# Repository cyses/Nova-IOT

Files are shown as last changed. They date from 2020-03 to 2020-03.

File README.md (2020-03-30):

<!DOCTYPE html><html><head><meta charset="utf-8"></head><body id="preview">
<h1 class="code-line" data-line-start=0 data-line-end=1>NovaIoT Cookbook</h1>

<p class="has-line-data" data-line-start="5" data-line-end="6">NovaIoT is an open-source framework that is made for spreading LoRa Sensors all over the world. NovaIoT package consists of two main parts:</p>
<ul>
<li class="has-line-data" data-line-start="6" data-line-end="7">The Hardware design for LoRa modules</li>
<li class="has-line-data" data-line-start="7" data-line-end="8">The Software design for LoRa sensors.</li>
<li class="has-line-data" data-line-start="8" data-line-end="10">And a little bit Magic :)</li>
</ul>
<h1 class="code-line" data-line-start=10 data-line-end=11>New Features!</h1>
<ul>

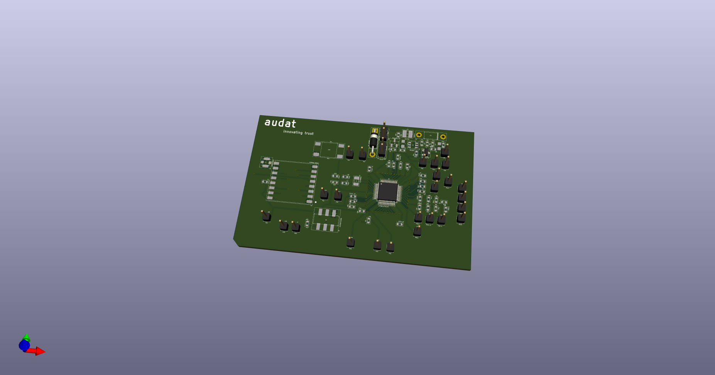
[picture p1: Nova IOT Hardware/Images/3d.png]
Build Status

<li class="has-line-data" data-line-start="12" data-line-end="13">You can visualize the sensor data in the GUI app with a RestFull API.</li>
</ul>
<p class="has-line-data" data-line-start="16" data-line-end="17">You can also:</p>
<ul>
<li class="has-line-data" data-line-start="17" data-line-end="18">Use the hardware design and print the PCB.</li>
<li class="has-line-data" data-line-start="18" data-line-end="19">With required components for PCB you can complete the sensor at all.</li>
<li class="has-line-data" data-line-start="19" data-line-end="20">You can use any IP67 case for the sensor. (We are going to upload the IP67 design soon if you want to use a ready one!)</li>
<li class="has-line-data" data-line-start="20" data-line-end="21">You can integrate the sensor on our server software. (which would be online soon!)</li>
<li class="has-line-data" data-line-start="21" data-line-end="22">You can use our GUI in order to visualize the sensor data (just think like mqtt)</li>
</ul>
<p class="has-line-data" data-line-start="24" data-line-end="25">Here there are several things that we need to mention before we start!</p>
<blockquote>
<p class="has-line-data" data-line-start="26" data-line-end="32">Our primer aim is to spread this LoRa sensors all over the world fastly.<br>
We really believe in the power of open-source<br>
and we are always open to commits and suggestions!<br>
Please feel free if you have an idea for making any of these technologies better<br>
We are ready to hear and make the system better!<br>
or if you just want to use the design, you are very welcome. But do not forget that, it is free for NON-COMMERCIAL use!</p>
</blockquote>
<h3 class="code-line" data-line-start=34 data-line-end=35>Tech</h3>
<p class="has-line-data" data-line-start="36" data-line-end="37">First lets mention what components should you use. The components in the lists required very hard work and took a lot of time in order to find them.</p>
<ul>
<li class="has-line-data" data-line-start="38" data-line-end="39">STM32L072CZT6 - The main microprocessor that we used in our PCB</li>
<li class="has-line-data" data-line-start="39" data-line-end="40">SX1276IMLTRT - the core component for LoRa</li>
<li class="has-line-data" data-line-start="40" data-line-end="41">Li/SOCL2 4000 mAH 3.6v connector 2.54mm Two batteries side by side with protection - this is the magic battery. :)</li>
<li class="has-line-data" data-line-start="41" data-line-end="42">RFM95W-868 - the integrated LoRa module</li>
</ul>
<h3 class="code-line" data-line-start=45 data-line-end=46>Installation</h3>
<p class="has-line-data" data-line-start="47" data-line-end="49">We are changing our software infrastructure in docker based containers. But of course that would take time. Until that time you can use our PHP applications for GUI and server. You can ask us anything if you tackle in somewhere.<br>
The requirements for now are;</p>
<ul>
<li class="has-line-data" data-line-start="50" data-line-end="51">PHP 7.2 +</li>
<li class="has-line-data" data-line-start="51" data-line-end="52">Apache</li>
<li class="has-line-data" data-line-start="52" data-line-end="53">MySQL</li>
</ul>
After completing the setup of docker infrastructure, you would be run the environment as
<pre><code class="has-line-data" data-line-start="56" data-line-end="60" class="language-sh">$ <span class="hljs-built_in">docker</span> compose up

</code></pre>
<h3 class="code-line" data-line-start=63 data-line-end=64>Todos</h3>
<ul>
<li class="has-line-data" data-line-start="65" data-line-end="66"><em>Docker container</em></li>
<li class="has-line-data" data-line-start="66" data-line-end="68">Improvements in hardware design in order to make the PCB smaller</li>
</ul>
<h2 class="code-line" data-line-start=68 data-line-end=70>License</h2>
<p class="has-line-data" data-line-start="71" data-line-end="72">MIT</p>
<p class="has-line-data" data-line-start="74" data-line-end="75"><strong>Free Software, Hell Yeah!</strong></p>
</body></html>

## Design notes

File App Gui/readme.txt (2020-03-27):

Thank you for choosing my software.
I spend some time for making documentation.
Please read documentation before trying to install, it will save time for you.
In case you have some questions or found bugs, don't hasitate to ask me, it's free;)
In case you need some additional functionality, don't hasitate to ask me, it's for money.

My email mail@noxls.net

Sincerely.

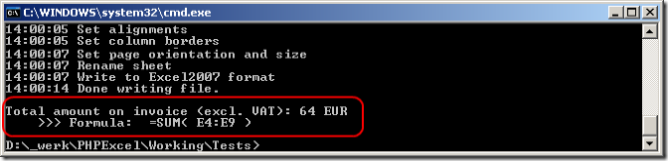
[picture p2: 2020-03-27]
App Gui/includes/classes/PhpSpreadsheet/Documentation/markdown/Overview/images/09-command-line-calculation.png

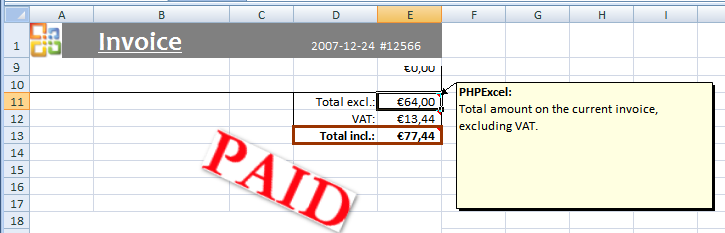
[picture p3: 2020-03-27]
App Gui/includes/classes/PhpSpreadsheet/Documentation/markdown/Overview/images/08-cell-comment.png

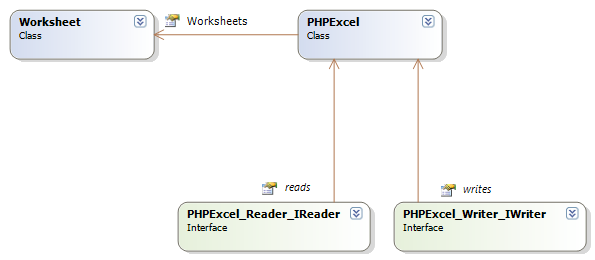
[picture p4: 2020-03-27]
App Gui/includes/classes/PhpSpreadsheet/Documentation/assets/ClassDiagrams/Architecture.png

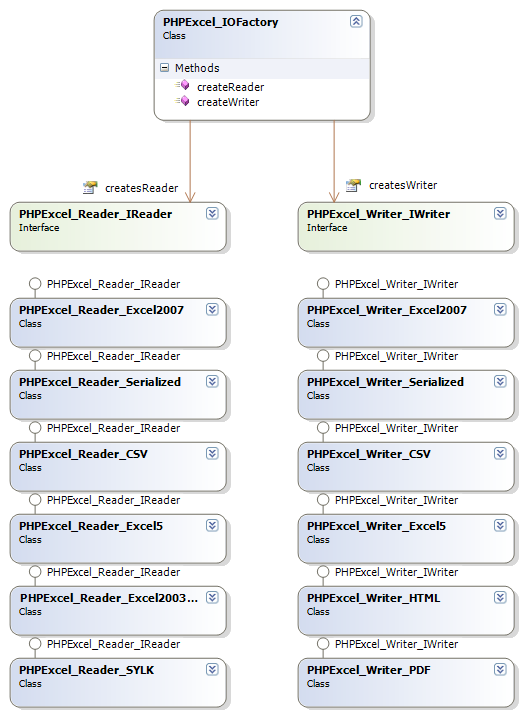
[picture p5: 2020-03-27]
App Gui/includes/classes/PhpSpreadsheet/Documentation/markdown/Overview/images/02-readers-writers.png

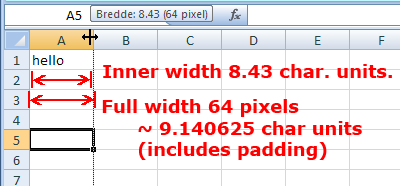
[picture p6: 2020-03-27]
App Gui/includes/classes/PhpSpreadsheet/Documentation/markdown/Overview/images/08-column-width.png

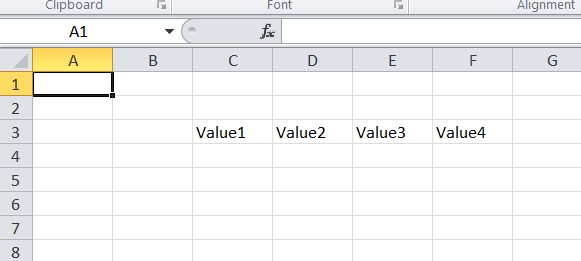
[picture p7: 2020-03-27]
App Gui/includes/classes/PhpSpreadsheet/Documentation/markdown/Overview/images/07-simple-example-3.png

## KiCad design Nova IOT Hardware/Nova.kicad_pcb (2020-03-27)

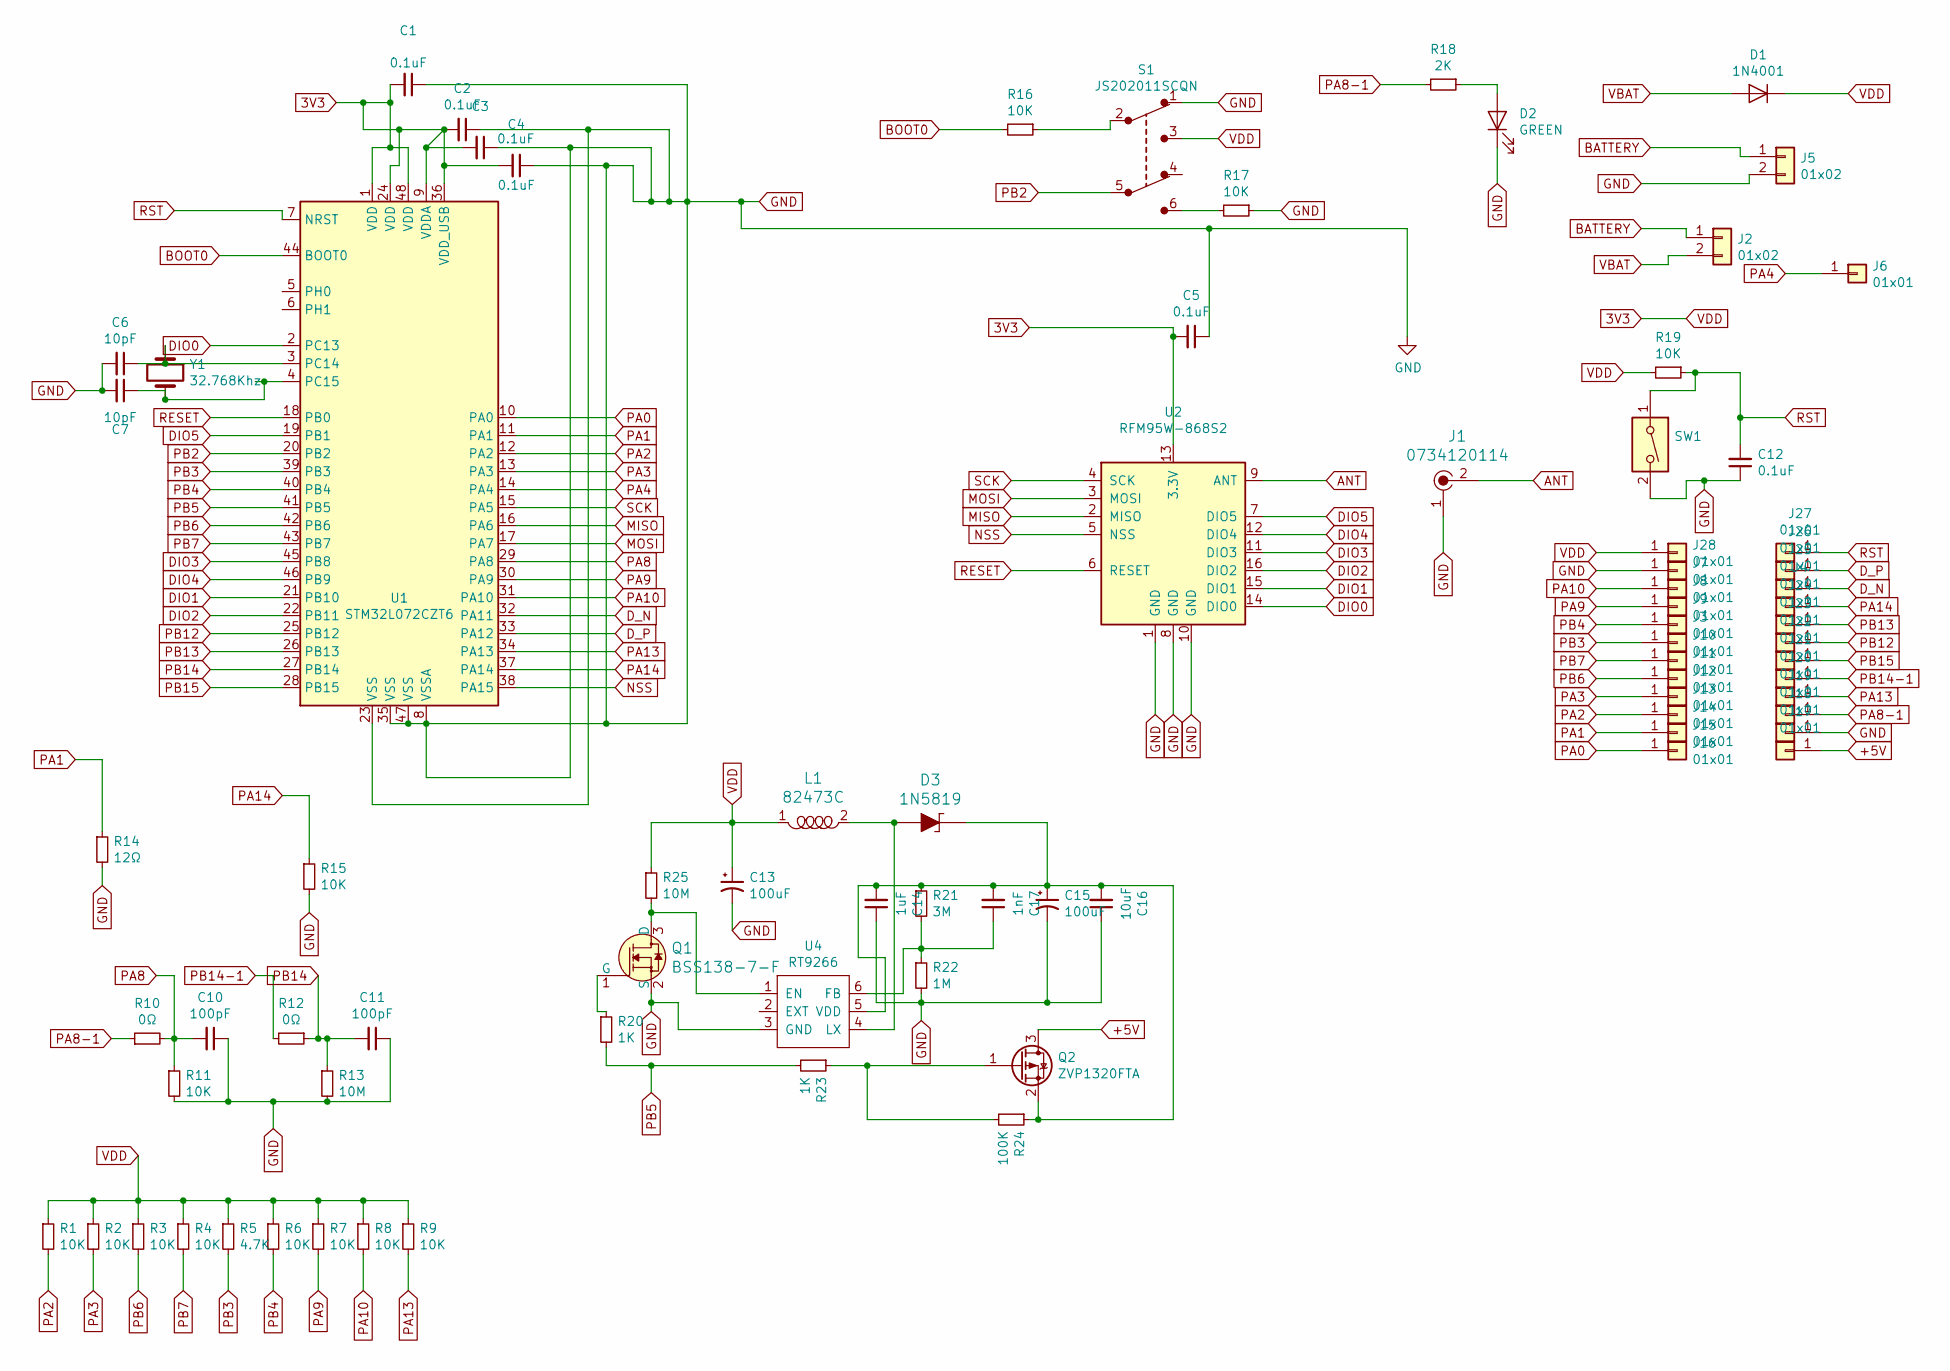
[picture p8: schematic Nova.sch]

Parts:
C1, C2, C3, C4, C5, C12: 0.1uF; 0603
C6, C7: 10pF; 0603
C10, C11: 100pF; 0603
C13, C15: 100uF; 0805
C14: 1uF; 0603
C16: 10uF; 0603
C17: 1nF; 0603
D1: 1N4001; D_DO-41_SOD81_P10.16mm_Horizontal
D2: GREEN; 0603
D3: 1N5819; DO-41; MPN 1N5819; Digi-Key_PN 1N5819FSCT-ND
J1: 0734120114; Molex_734120114_UMC_RF_CONN_Vertical; MPN 0734120114; Digi-Key_PN WM3894CT-ND
J2, J5: 01x02; PinHeader_1x02_P2.54mm_Vertical
J3, J4, J6, J7, J8, J9, J10, J11, J12, J13, J14, J15, J16, J17, J18, J19, J20, J21, J22, J23, J24, J25, J26, J27, J28: 01x01; PinHeader_1x01_P2.54mm_Vertical
L1: 82473C; 1210; MPN 82473C; Digi-Key_PN 811-2477-1-ND
Q1: BSS138-7-F; SOT-23-3; MPN BSS138-7-F; Digi-Key_PN BSS138-FDICT-ND
Q2: ZVP1320FTA; SOT-23
R1, R2, R3, R4, R6, R7, R8, R9, R11, R15, R16, R17, R19: 10K; 0603
R5: 4.7K; 0603
R10, R12: 0Ω; 0603
R13, R25: 10M; 0603
R14: 12Ω; 0603
R18: 2K; 0603
R20, R23: 1K; 0603
R21: 3M; 0603
R22: 1M; 0603
R24: 100K; 0603
S1: JS202011SCQN; Switch_Slide_JS202011SCQN; MPN JS202011SCQN; Digi-Key_PN 401-2002-1-ND
SW1: SW; Switch_Tactile_SMD_6x6mm
U1: STM32L072CZT6; LQFP-48_7x7mm_P0.5mm
U2: RFM95W-868S2; XCVR_RFM95W-868S2
U4: RT9266; SOT-23-6
Y1: 32.768Khz; SMD-2_3.2x1.5mm

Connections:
3V3: C1.2, C2.2, C3.2, C4.2, C5.2, C13.1, D1.1 (K), J28.1, L1.1, R1.1, R2.1, R3.1, R4.1, R5.1, R6.1, R7.1, R8.1, R9.1, R19.2, R25.1, S1.3, U1.1 (VDD), U1.9 (VDDA), U1.24 (VDD), U1.36 (VDD_USB), U1.48 (VDD), U2.13 (3.3V)
+5V: J17.1, Q2.3 (D)
ANT: J1.2, U2.9 (ANT)
BATTERY: J2.1, J5.1
BOOT0: R16.2, U1.44 (BOOT0)
DIO0: U1.2 (PC13), U2.14 (DIO0)
DIO1: U1.21 (PB10), U2.15 (DIO1)
DIO2: U1.22 (PB11), U2.16 (DIO2)
DIO3: U1.45 (PB8), U2.11 (DIO3)
DIO4: U1.46 (PB9), U2.12 (DIO4)
DIO5: U1.19 (PB1), U2.7 (DIO5)
D_N: J25.1, U1.32 (PA11)
D_P: J26.1, U1.33 (PA12)
GND: C1.1, C2.1, C3.1, C4.1, C5.1, C6.2, C7.2, C10.1, C11.1, C12.1, C13.2, C14.1, C15.2, C16.1, D2.1 (K), J1.1, J5.2, J7.1, J18.1, Q1.2 (S), R11.2, R13.2, R14.2, R15.2, R17.1, R22.2, S1.1, SW1.2, U1.8 (VSSA), U1.23 (VSS), U1.35 (VSS), U1.47 (VSS), U2.1 (GND), U2.8 (GND), U2.10 (GND), U4.3 (GND)
MISO: U1.16 (PA6), U2.2 (MISO)
MOSI: U1.17 (PA7), U2.3 (MOSI)
NSS: U1.38 (PA15), U2.5 (NSS)
unnamed: C6.1, U1.3 (PC14), Y1.1
unnamed: C7.1, U1.4 (PC15), Y1.2
unnamed: C14.2, C15.1, C16.2, C17.2, D3.K, Q2.2 (S), R21.1, R24.1, U4.5 (VDD)
unnamed: C17.1, R21.2, R22.1, U4.6 (FB)
unnamed: D2.2 (A), R18.1
unnamed: D3.A, L1.2, U4.4 (LX)
unnamed: Q1.1 (G), R20.1
unnamed: Q1.3 (D), R25.2, U4.1 (EN)
unnamed: Q2.1 (G), R23.1, R24.2
unnamed: R16.1, S1.2
unnamed: R17.2, S1.6
PA0: J16.1, U1.10 (PA0)
PA1: J15.1, R14.1, U1.11 (PA1)
PA2: J14.1, R1.2, U1.12 (PA2)
PA3: J13.1, R2.2, U1.13 (PA3)
PA4: J6.1, U1.14 (PA4)
PA8: C10.2, R10.2, R11.1, U1.29 (PA8)
PA8-1: J19.1, R10.1, R18.2
PA9: J9.1, R7.2, U1.30 (PA9)
PA10: J8.1, R8.2, U1.31 (PA10)
PA13: J20.1, R9.2, U1.34 (PA13)
PA14: J4.1, R15.1, U1.37 (PA14)
PB2: S1.5, U1.20 (PB2)
PB3: J10.1, R5.2, U1.39 (PB3)
PB4: J3.1, R6.2, U1.40 (PB4)
PB5: R20.2, R23.2, U1.41 (PB5)
PB6: J12.1, R3.2, U1.42 (PB6)
PB7: J11.1, R4.2, U1.43 (PB7)
PB12: J23.1, U1.25 (PB12)
PB13: J24.1, U1.26 (PB13)
PB14: C11.2, R12.1, R13.1, U1.27 (PB14)
PB14-1: J21.1, R12.2
PB15: J22.1, U1.28 (PB15)
RESET: U1.18 (PB0), U2.6 (RESET)
RST: C12.2, J27.1, R19.1, SW1.1, U1.7 (NRST)
SCK: U1.15 (PA5), U2.4 (SCK)
VBAT: D1.2 (A), J2.2

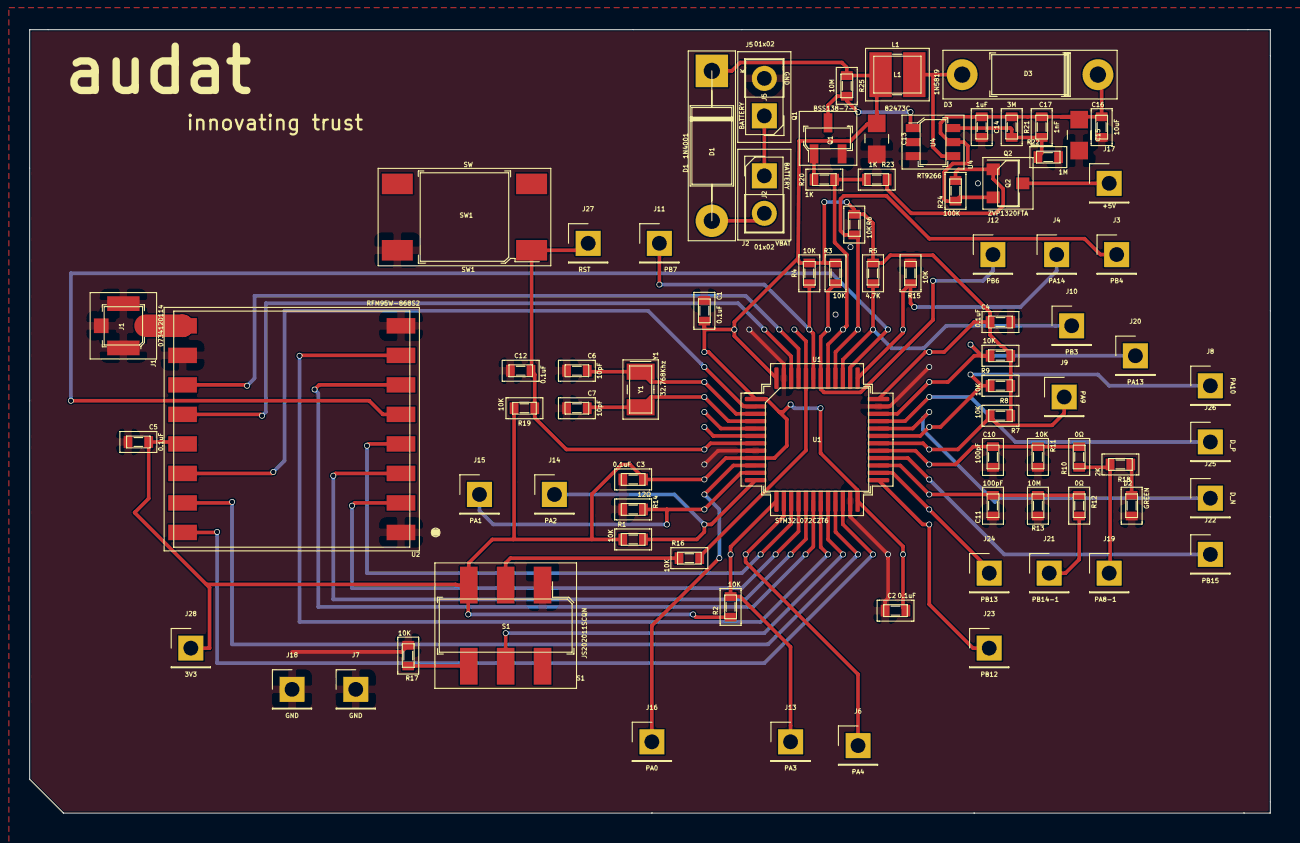
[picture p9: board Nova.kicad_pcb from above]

Board: 2 copper layers, 84.1 x 53.1 mm, 80 parts (0 on the bottom side), 54 nets.

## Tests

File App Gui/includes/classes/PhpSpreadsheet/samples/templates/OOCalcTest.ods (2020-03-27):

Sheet: Sample Data
Test String 1 | 1 | 5 |  | A | E |  | 6 |  | AE
Test - String 2 | 2 | 6 |  | B | F |  | 8 |  | BF |  |  | Dot
Test #3 | 3 | 7 |  | C | G |  | 10 |  | CG | Red | Red | Dash
Test with (") in string | 4 | 8 |  | D | H |  | 12 |  | DH | Orange | Orange | Dash/Dot/Dot
 |  |  |  |  |  |  | 10 | 26 | 36 | Yellow | Yellow | Dash/Dot
Test #3 | 1.23 | TRUE | TRUE |  |  |  |  |  |  | Green | Green | Thin Line
Test #3 | 2.34 | FALSE | FALSE |  |  |  | #NAME? |  |  | Blue | Blue | Thick Dash/Dot/Dot
Test #3 | 3.45 |  |  |  |  |  |  |  |  | Purple | Purple | Variant Thick Dash/Dot/Dot
 |  |  |  |  |  |  |  |  |  | Pink | Pink | Thick Dash/Dot
19/12/1960 |  | TOP |  |  |  | 0 |  |  |  | Brown | Brown | Thick Dash
1 1/2 |  |  |  |  |  | #DIV/0! |  |  |  |  |  | Thick Line
 |  | BOTTOM |  |  |  |  |  |  |  |  |  | Extra Thick Line
02:30:00 |  |  |  |  | Мойва сушеная |  |  |  |  |  |  | Double Line
 |  | LEFT |  |  | Ärendetext
19/12/60 01:30 |  |  |  |  | Højde
 |  | RIGHT
 | BOX |  |  |  |  | Test Column 1
 |  |  |  |  |  |  | Test Column 2 |  |  | Patterned | Patterned 2
 |  |  |  |  |  |  |  | Test Column 3
Underline None |  | Rotate 90 |  | Rotate 45 |  | Rotate -90 |  | Rotate -45
Underline 1 | Subscript
Underline 2 | Superscript
Underline 3
Underline 4
I don't know if OOCalc supports Rich Text in the same way as Excel, And this row should be autofit height with text wrap
PHPExcel (http://www.phpexcel.net/)

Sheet: Report Data
Heading 1 | Heading 2 | Third Heading | Date Heading | Time Heading | Adjusted Date | Adjusted Number
ABC | 1 | 1.11 | 01-Jan-2001 | 01:00 AM | 31-Dec-2000 | 1.11 | A | 1A
BCD | 2 | 2.22 | 02-Feb-2002 | 02:00 AM | 31-Jan-2002 | 4.44 | B | 2B
CDE | 3 | 3.33 | 03-Mar-2003 | 03:00 AM | 28-Feb-2003 | 9.99 | C | 3C
DEF | 4 | 4.44 | 03-Apr-2004 | 04:00 AM | 30-Mar-2004 | 17.76 | D | 4D
EFG | 5 | 5.55 | 04-May-2005 | 05:00 AM | 29-Apr-2005 | 27.75 | E | 5E
FGH | 6 | 6.66 | 05-Jun-2006 | 06:00 AM | 30-May-2006 | 39.96 | F | 6F
GHI | 7 | 7.77 | 06-Jul-2007 | 07:00 AM | 29-Jun-2007 | 54.39 | G | 7G
HIJ | 8 | 8.88 | 07-Aug-2008 | 08:00 AM | 30-Jul-2008 | 71.04 | H | 8H
IJK | 9 | 9.99 | 08-Sep-2009 | 09:00 AM | 30-Aug-2009 | 89.91 | I | 9I
JKL | 10 | 11.10 | 09-Oct-2010 | 10:00 AM | 29-Sep-2010 | 111.00 | J | 10J
KLM | 11 | 12.21 | 11-Nov-2011 | 11:00 AM | 31-Oct-2011 | 134.31 | K | 11K
LMN | 12 | 13.32 | 12-Dec-2012 | 12:00 AM | 30-Nov-2012 | 159.84 | L | 12L
ZYX | -1 | 1.11 | 01-Dec-1999 | 11:00 PM | 02-Dec-1999 | 1.11 | M | -1M

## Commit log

2020-03-27 Add files Nova-IOT
    [26template.xlsx, 27template.xls, 28iterators.xlsx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]
2020-03-27 Change files Nova-IOT
    [26template.xlsx, 27template.xls, 28iterators.xlsx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]
